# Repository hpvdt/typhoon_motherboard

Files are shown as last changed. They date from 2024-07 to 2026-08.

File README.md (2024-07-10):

# Typhoon Motherboard

General template repository for our hardware projects, especially one-off and self-contained projects like custom test equipment. This template assumes that the hardware is being designed in KiCad.

## Organization

Pretty self-explanitory, put hardware related files into the `hardware` folder, firmware in the `firmware` folder. Other folders can be added as needed: for example a `media` folder is handy for storing pictures related to a project which can be used in documentation.

## Conventions

Partly for consistency, partly for functionality; please follow the following conventions:

- Try to keep folder names to single words and all lowercase
- Use underscores to separate words in names (e.g. `board_rev1`). **DO NOT USE SPACES! ESPECIALLY FOR FOLDERS CONTAINING CODE!** Spaces in file paths may cause issues in compilers and such so best to avoid them entirely.

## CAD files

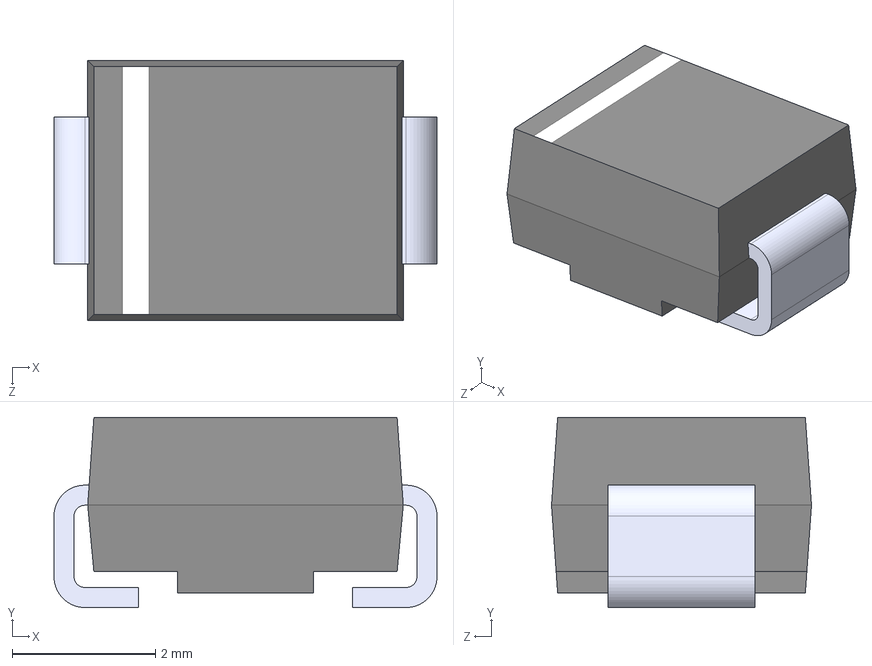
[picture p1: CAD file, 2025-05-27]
hardware/footprint/SMBJ5.0A/SMBJ5.0A.step
5.34 x 2.65 x 3.62 mm

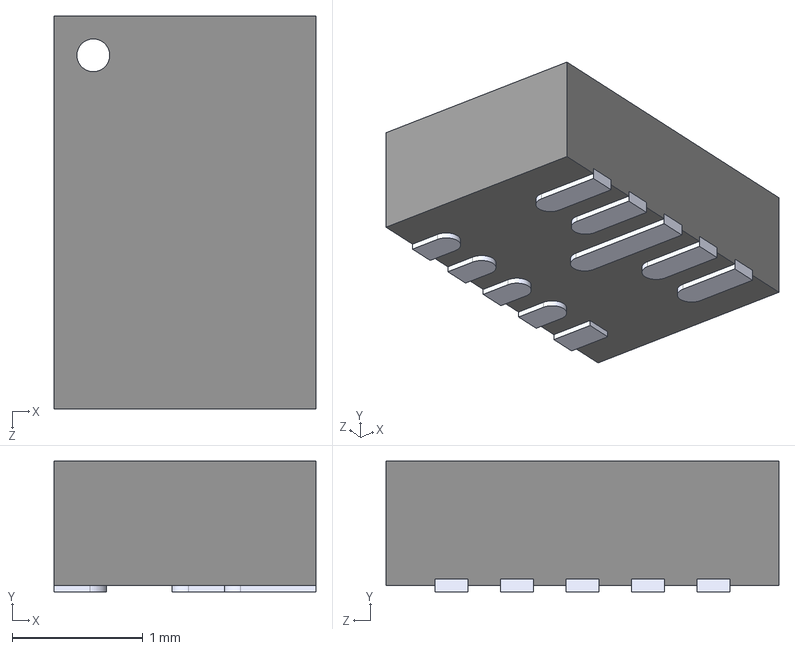
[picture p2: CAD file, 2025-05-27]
hardware/footprint/TPS63802DLAR (1)/TPS63802DLAR.step
2.00 x 1.00 x 3.00 mm

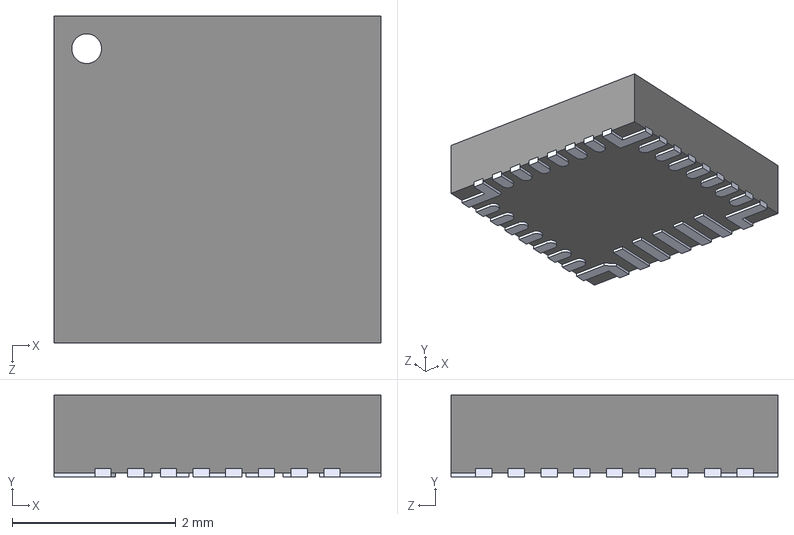
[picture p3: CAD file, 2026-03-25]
hardware/rev2/parts/BQ25798RQMR/BQ25798RQMR.step
4.00 x 1.00 x 4.00 mm

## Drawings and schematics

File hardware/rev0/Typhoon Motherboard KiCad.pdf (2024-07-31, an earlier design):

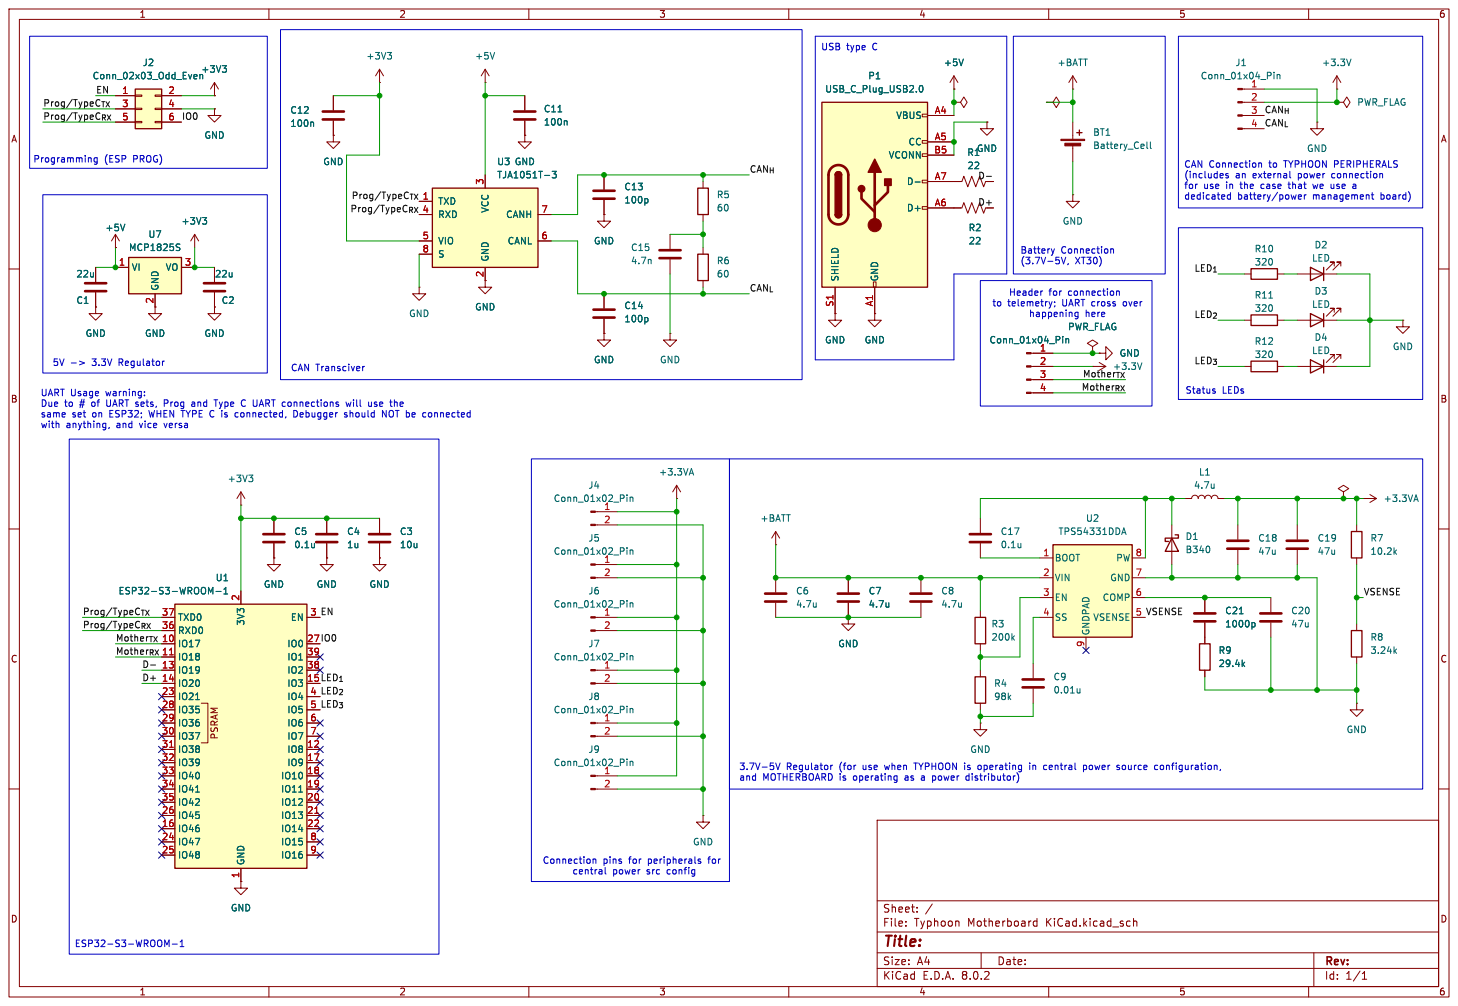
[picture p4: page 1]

for use in the case that we use a

3 RXD 4 VIO 5 CANL 6 CANH 7 S

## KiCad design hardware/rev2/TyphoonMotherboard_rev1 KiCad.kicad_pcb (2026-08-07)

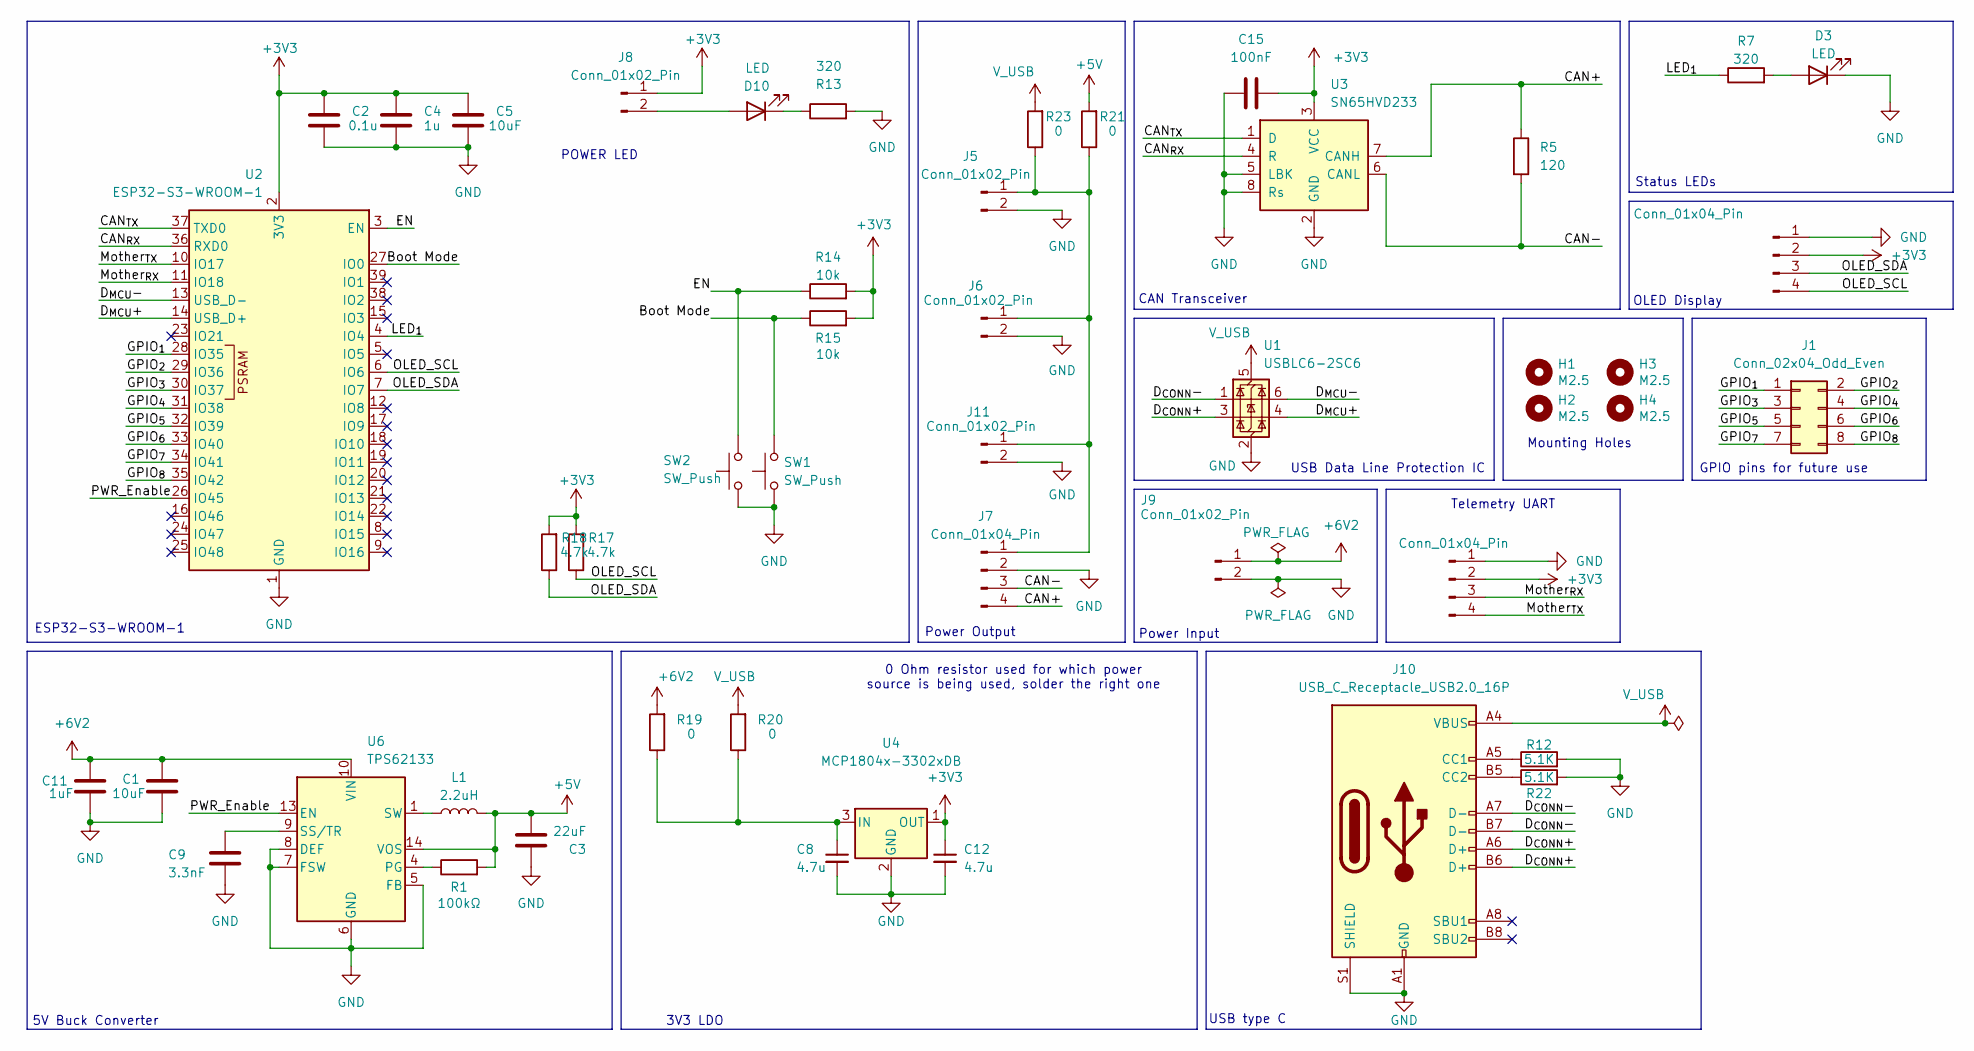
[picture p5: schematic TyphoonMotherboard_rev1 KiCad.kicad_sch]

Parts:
C1: 10uF; C_0603_1608Metric
C2: 0.1u; C_0603_1608Metric; Manufacturer Part Number CL10B105KP8NNNC
C3: 22uF; C_0603_1608Metric
C4: 1u; C_0603_1608Metric; Manufacturer Part Number C0603C104K5RACTU
C5: 10uF; C_0603_1608Metric; Manufacturer Part Number CL10A106KQ8NNNC
C8, C12: 4.7u; C_0603_1608Metric; LCSC C1779
C9: 3.3nF; C_0603_1608Metric
C11: 1uF; C_0603_1608Metric
C15: 100nF; C_0603_1608Metric; Manufacturer Part Number CL10E104KC8VPNC
D3, D10: LED; LED_0805_2012Metric; Manufacturer Part Number LTST-C171GKT
H1, H2, H3, H4: M2.5; MountingHole_2.7mm_M2.5
J1: Conn_02x04_Odd_Even; PinSocket_2x04_P2.54mm_Vertical
J2, J4, J7: Conn_01x04_Pin; JST_XH_B4B-XH-A_1x04_P2.50mm_Vertical
J5, J6, J9, J11: Conn_01x02_Pin; JST_XH_B2B-XH-A_1x02_P2.50mm_Vertical
J8: Conn_01x02_Pin; PinHeader_1x02_P2.54mm_Vertical
J10: USB_C_Receptacle_USB2.0_16P; USB_C_Receptacle_JAE_DX07S016JA1R1500; Manufacturer Part Number DX07S016JA3R1500
L1: 2.2uH; L_0805_2012Metric
R1: 100kΩ; R_0603_1608Metric
R5: 120; R_0603_1608Metric
R7: 320; R_0603_1608Metric; Manufacturer Part Number RT0603DRE07320RL
R12, R22: 5.1K; R_0603_1608Metric; Manufacturer Part Number RC0603FR-075K1L
R13: 320; R_0603_1608Metric; Manufacturer Part Number ERA-3AEB331V
R14, R15: 10k; R_0603_1608Metric; Manufacturer Part Number RMCF0603JT10K0
R17, R18: 4.7k; R_0603_1608Metric; Manufacturer Part Number RMCF0603JT10K0
R19, R20, R21, R23: 0; R_1206_3216Metric; Manufacturer Part Number RMCF0603JT10K0
SW1, SW2: SW_Push; SMT_FS
U1: USBLC6-2SC6; SOT-23-6; Manufacturer Part Number USBLC6-2SC6; Digikey Part Number 497-5235-1-ND
U2: ESP32-S3-WROOM-1; Manufacturer Part Number ESP32-S3-WROOM-1-N4R8
U3: SN65HVD233; SOIC-8_3.9x4.9mm_P1.27mm; Manufacturer Part Number SN65HVD233DR
U4: MCP1804x-3302xDB; SOT-223-3_TabPin2
U6: TPS62133; VQFN-16-1EP_3x3mm_P0.5mm_EP1.68x1.68mm_ThermalVias

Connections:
+3V3: C2.1, C4.1, C5.1, C12.1, C15.2, J2.2, J4.2, J8.1, R14.2, R15.2, R17.2, R18.2, U2.2 (3V3), U3.3 (VCC), U4.1 (OUT)
+5V: C3.2, L1.2, R1.2, R21.2, U6.14 (VOS)
+6V2: C1.2, C11.2, J9.1, R19.2, U6.10 (VIN), U6.11 (VIN), U6.12 (VIN)
/Boot Mode: R15.1, SW1.2, U2.27 (IO0)
/CAN+: J7.4, R5.1, U3.7 (CANH)
/CAN-: J7.3, R5.2, U3.6 (CANL)
/CAN_{RX}: U2.36 (RXD0), U3.4 (R)
/CAN_{TX}: U2.37 (TXD0), U3.1 (D)
/D_{CONN}+: J10.A6 (D+), J10.B6 (D+), U1.3 (I/O2)
/D_{CONN}-: J10.A7 (D-), J10.B7 (D-), U1.1 (I/O1)
/D_{MCU}+: U1.4 (I/O2), U2.14 (USB_D+)
/D_{MCU}-: U1.6 (I/O1), U2.13 (USB_D-)
/EN: R14.1, SW2.2, U2.3 (EN)
/GPIO_{1}: J1.1, U2.28 (IO35)
/GPIO_{2}: J1.2, U2.29 (IO36)
/GPIO_{3}: J1.3, U2.30 (IO37)
/GPIO_{4}: J1.4, U2.31 (IO38)
/GPIO_{5}: J1.5, U2.32 (IO39)
/GPIO_{6}: J1.6, U2.33 (IO40)
/GPIO_{7}: J1.7, U2.34 (IO41)
/GPIO_{8}: J1.8, U2.35 (IO42)
/LED_{1}: R7.1, U2.4 (IO4)
/Mother_{RX}: J2.3, U2.11 (IO18)
/Mother_{TX}: J2.4, U2.10 (IO17)
/OLED_SCL: J4.4, R17.1, U2.6 (IO6)
/OLED_SDA: J4.3, R18.1, U2.7 (IO7)
/PWR_Enable: U2.26 (IO45), U6.13 (EN)
GND: C1.1, C2.2, C3.1, C4.2, C5.2, C8.2, C9.1, C11.1, C12.2, C15.1, D3.1 (K), J2.1, J4.1, J5.2, J6.2, J7.2, J9.2, J10.A1 (GND), J10.A12 (GND), J10.B1 (GND), J10.B12 (GND), J10.S1 (SHIELD), J11.2, R12.2, R13.2, R22.2, SW1.1, SW2.1, U1.2 (GND), U2.1 (GND), U2.40 (GND), U2.41 (GND), U3.2 (GND), U3.5 (LBK), U3.8 (Rs), U4.2 (GND), U6.5 (FB), U6.6 (GND), U6.7 (FSW), U6.8 (DEF), U6.15 (GND), U6.16 (GND), U6.17 (GND)
unnamed: D3.2 (A), R7.2
unnamed: D10.2 (A), J8.2
unnamed: D10.1 (K), R13.1
unnamed: J10.A5 (CC1), R12.1
unnamed: J10.B5 (CC2), R22.1
unnamed: J5.1, J6.1, J7.1, J11.1, R21.1, R23.1
unnamed: L1.1, U6.1 (SW), U6.2 (SW), U6.3 (SW)
unnamed: C8.1, R19.1, R20.1, U4.3 (IN)
unnamed: R1.1, U6.4 (PG)
unnamed: C9.2, U6.9 (SS/TR)
V_USB: J10.A4 (VBUS), J10.A9 (VBUS), J10.B4 (VBUS), J10.B9 (VBUS), R20.2, R23.2, U1.5 (VBUS)

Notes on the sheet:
Status LEDs
Power Input
ESP32-S3-WROOM-1
USB Data Line Protection IC
CAN Transceiver
5V Buck Converter
3V3 LDO
OLED Display
GPIO pins for future use
Mounting Holes
Power Output
POWER LED
0 Ohm resistor used for which power source is being used, solder the right one
USB type C
Telemetry UART

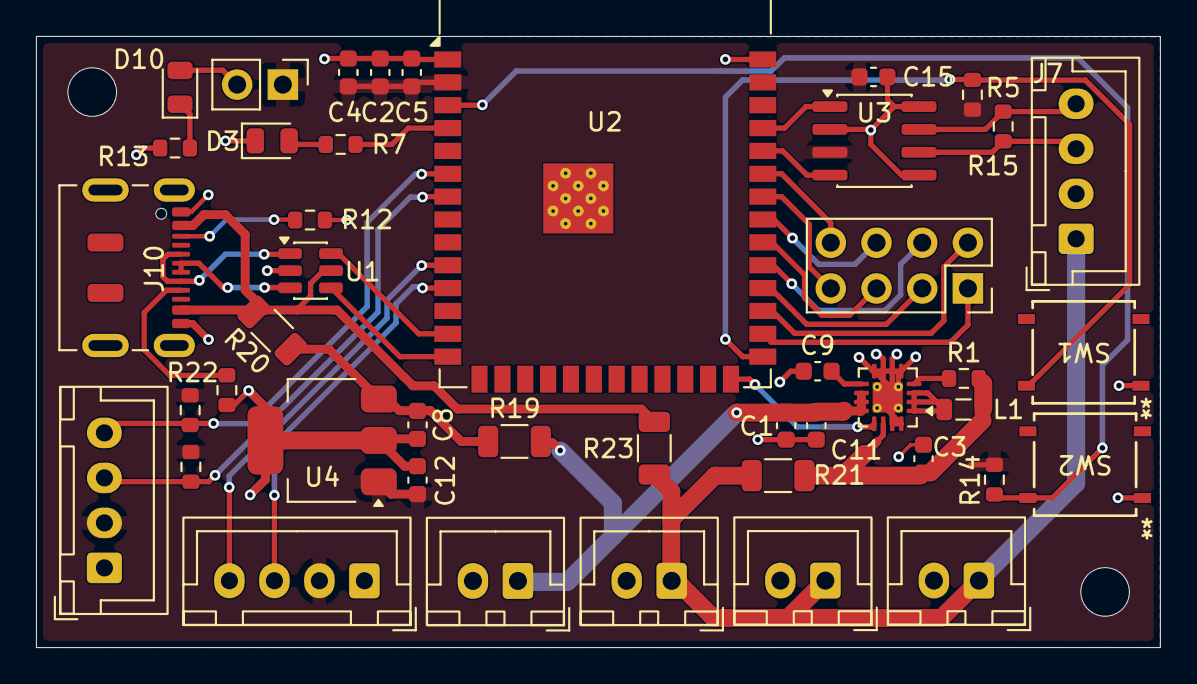
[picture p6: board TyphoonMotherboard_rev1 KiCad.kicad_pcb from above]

Board: 2 copper layers, 62.4 x 33.9 mm, 48 parts (0 on the bottom side), 39 nets.

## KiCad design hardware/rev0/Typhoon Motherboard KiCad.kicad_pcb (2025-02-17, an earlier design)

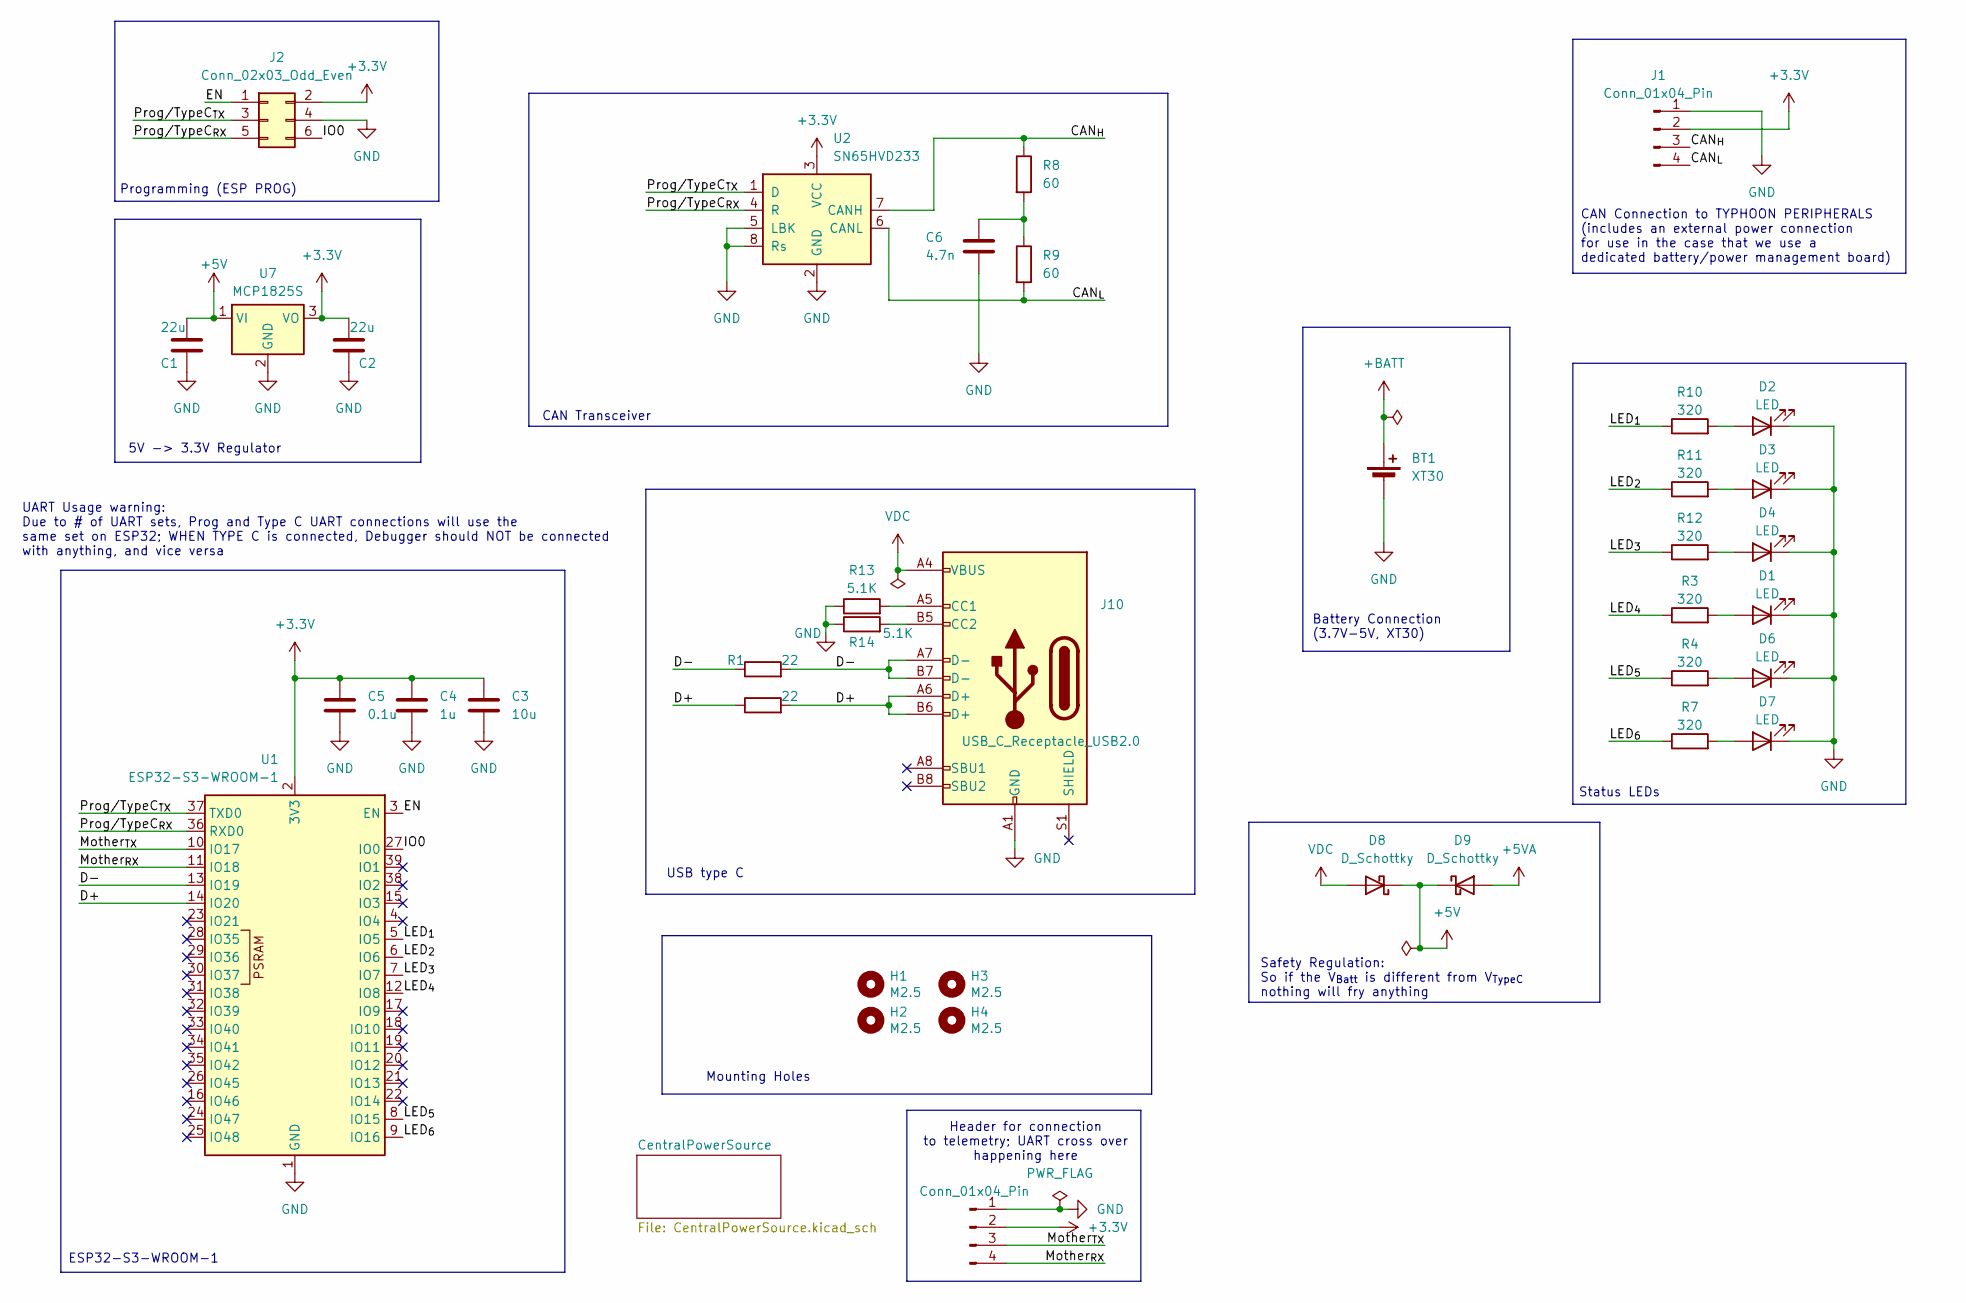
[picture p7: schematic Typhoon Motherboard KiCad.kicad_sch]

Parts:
BT1: XT30; AMASS_XT30PW-M_1x02_P2.50mm_Horizontal
C1, C2: 22u; C_0603_1608Metric
C3: 10u; C_0603_1608Metric
C4: 1u; C_0603_1608Metric
C5: 0.1u; C_0603_1608Metric
C6: 4.7n; C_0603_1608Metric
D1, D2, D3, D4, D6, D7: LED; LED_0805_2012Metric
D8, D9: D_Schottky; D_SOD-123
H1, H2, H3, H4: M2.5; MountingHole_2.7mm_M2.5
J1: Conn_01x04_Pin; JST_EH_S4B-EH_1x04_P2.50mm_Horizontal
J2: Conn_02x03_Odd_Even; IDC-Header_2x03_P2.54mm_Vertical
J3: Conn_01x04_Pin; PinHeader_1x04_P1.27mm_Vertical
J10: USB_C_Receptacle_USB2.0; USB_C_Receptacle_HRO_TYPE-C-31-M-12
R1, R2: 22; R_0603_1608Metric
R3, R4, R7, R10, R11, R12: 320; R_0603_1608Metric
R8, R9: 60; R_0603_1608Metric
R13, R14: 5.1K; R_0603_1608Metric
U1: ESP32-S3-WROOM-1
U2: SN65HVD233; SOIC-8_3.9x4.9mm_P1.27mm
U7: MCP1825S; SOT-223-3_TabPin2

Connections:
+3.3V: C2.2, C3.1, C4.1, C5.1, J1.2, J2.2, J3.2, U1.2 (3V3), U2.3 (VCC), U7.3 (VO)
+5V: C1.2, D8.1 (K), D9.1 (K), U7.1 (VI)
+5VA: D9.2 (A); also elsewhere on the board
+BATT: BT1.1 (+); also elsewhere on the board
/CAN_{H}: J1.3, R8.1, U2.7 (CANH)
/CAN_{L}: J1.4, R9.2, U2.6 (CANL)
/EN: J2.1, U1.3 (EN)
/IO0: J2.6, U1.27 (IO0)
/LED_{1}: R10.1, U1.5 (IO5)
/LED_{2}: R11.1, U1.6 (IO6)
/LED_{3}: R12.1, U1.7 (IO7)
/LED_{4}: R3.1, U1.12 (IO8)
/LED_{5}: R4.1, U1.8 (IO15)
/LED_{6}: R7.1, U1.9 (IO16)
/Mother_{RX}: J3.4, U1.11 (IO18)
/Mother_{TX}: J3.3, U1.10 (IO17)
/Prog/TypeC_{RX}: J2.5, U1.36 (RXD0), U2.4 (R)
/Prog/TypeC_{TX}: J2.3, U1.37 (TXD0), U2.1 (D)
GND: BT1.2 (-), C1.1, C2.1, C3.2, C4.2, C5.2, C6.2, D1.1 (K), D2.1 (K), D3.1 (K), D4.1 (K), D6.1 (K), D7.1 (K), J1.1, J2.4, J3.1, J10.A1 (GND), J10.A12 (GND), J10.B1 (GND), J10.B12 (GND), R13.1, R14.1, U1.1 (GND), U1.40 (GND), U1.41 (GND), U2.2 (GND), U2.5 (LBK), U2.8 (Rs), U7.2 (GND); also elsewhere on the board
unnamed: C6.1, R8.2, R9.1
unnamed: D1.2 (A), R3.2
unnamed: D2.2 (A), R10.2
unnamed: D3.2 (A), R11.2
unnamed: D4.2 (A), R12.2
unnamed: D6.2 (A), R4.2
unnamed: D7.2 (A), R7.2
unnamed: J10.A5 (CC1), R13.2
unnamed: J10.B5 (CC2), R14.2
VDC: D8.2 (A), J10.A4 (VBUS), J10.A9 (VBUS), J10.B4 (VBUS), J10.B9 (VBUS)

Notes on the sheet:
Header for connection to telemetry; UART cross over happening here
Battery Connection (3.7V-5V, XT30)
Programming (ESP PROG)
Status LEDs
CAN Connection to TYPHOON PERIPHERALS (includes an external power connection for use in the case that we use a dedicated battery/power management board)
Safety Regulation: So if the V_{Batt} is different from V_{TypeC} nothing will fry anything
Mounting Holes
5V -> 3.3V Regulator
USB type C
ESP32-S3-WROOM-1
CAN Transceiver
UART Usage warning: Due to # of UART sets, Prog and Type C UART connections will use the same set on ESP32; WHEN TYPE C is connected, Debugger should NOT be connected with anything, and vice versa

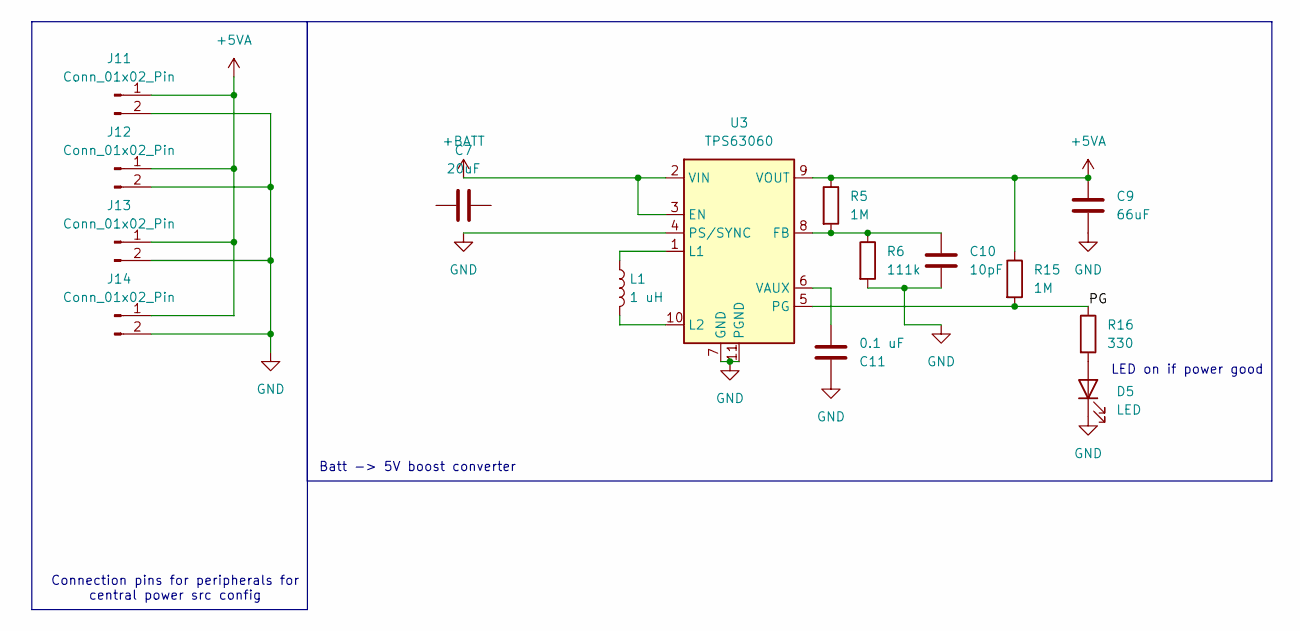
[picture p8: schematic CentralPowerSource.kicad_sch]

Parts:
C7: 20uF; C_0603_1608Metric
C9: 66uF; C_0603_1608Metric
C10: 10pF; C_0603_1608Metric
C11: 0.1 uF; C_0603_1608Metric
D5: LED; LED_0805_2012Metric
J11, J12, J13, J14: Conn_01x02_Pin; JST_EH_S2B-EH_1x02_P2.50mm_Horizontal
L1: 1 uH; L_0805_2012Metric
R5, R15: 1M; R_0603_1608Metric
R6: 111k; R_0603_1608Metric
R16: 330; R_0603_1608Metric
U3: TPS63060; Texas_S-PWSON-N10_ThermalVias

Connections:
+5VA: C9.1, J11.1, J12.1, J13.1, J14.1, R5.1, R15.1, U3.9 (VOUT); also elsewhere on the board
+BATT: U3.2 (VIN), U3.3 (EN); also elsewhere on the board
/CentralPowerSource/PG: R15.2, R16.1, U3.5 (PG)
GND: C9.2, C10.2, C11.1, D5.1 (K), J11.2, J12.2, J13.2, J14.2, R6.2, U3.4 (PS/SYNC), U3.7 (GND), U3.11 (PGND); also elsewhere on the board
unnamed: D5.2 (A), R16.2
unnamed: C10.1, R5.2, R6.1, U3.8 (FB)
unnamed: L1.1, U3.1 (L1)
unnamed: L1.2, U3.10 (L2)
unnamed: C11.2, U3.6 (VAUX)

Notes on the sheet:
Batt -> 5V boost converter
Connection pins for peripherals for central power src config
LED on if power good

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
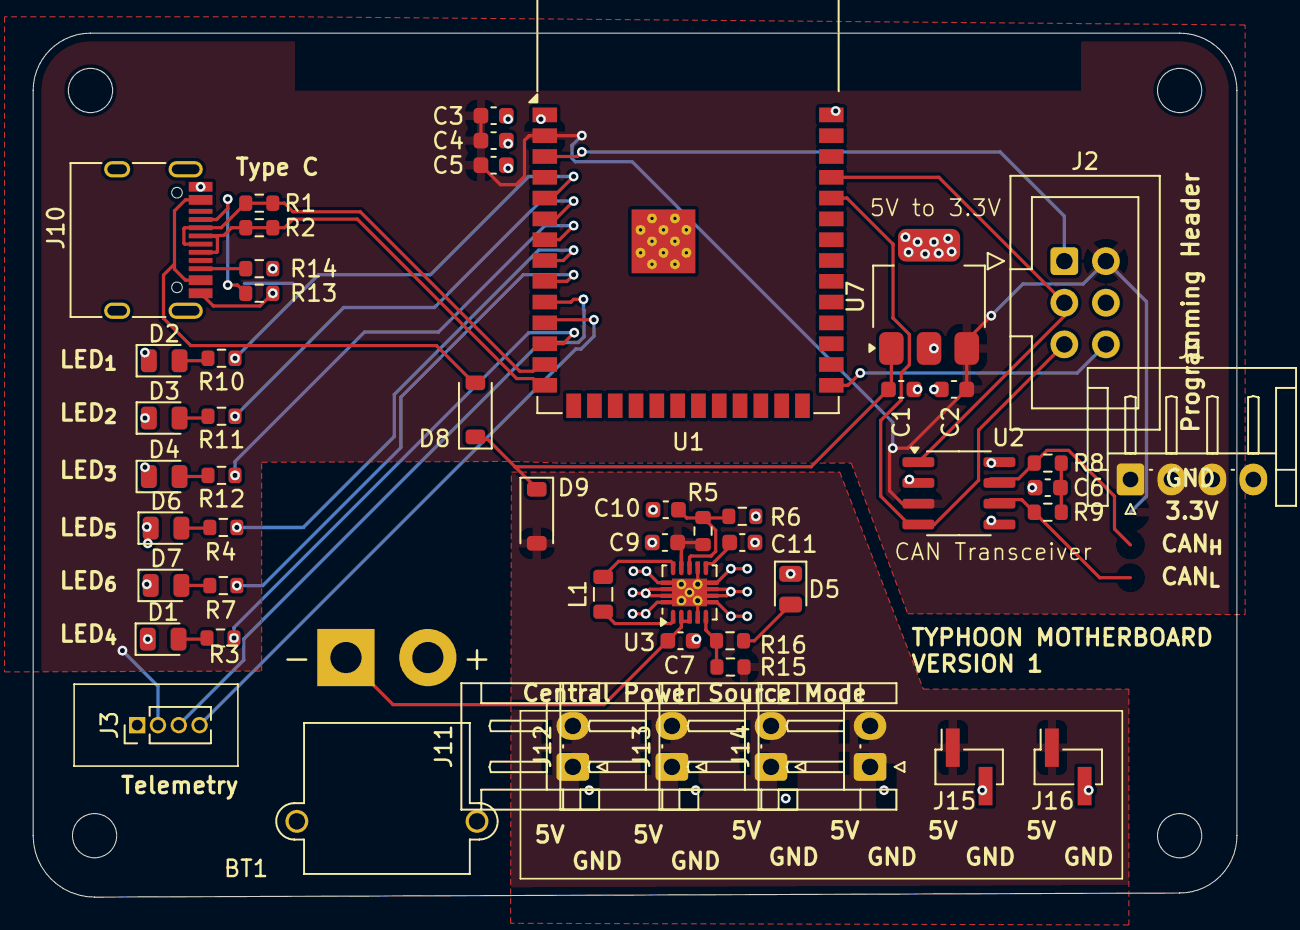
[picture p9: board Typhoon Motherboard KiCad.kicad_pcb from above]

Board: 2 copper layers, 73.5 x 52.8 mm, 55 parts (0 on the bottom side), 39 nets.

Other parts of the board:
J15, J16: Conn_01x02_Pin; PinHeader_1x02_P2.00mm_Vertical_SMD_Pin1Right

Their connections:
+5VA: J15.1, J16.1; also elsewhere on the board
GND: J15.2, J16.2; also elsewhere on the board

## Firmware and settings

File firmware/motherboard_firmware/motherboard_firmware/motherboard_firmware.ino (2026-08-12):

#include <Arduino.h>
#include "driver/twai.h"

constexpr gpio_num_t CAN_TX_PIN = GPIO_NUM_43;
constexpr gpio_num_t CAN_RX_PIN = GPIO_NUM_44;

constexpr uint32_t LED_COMMAND_ID = 0x200;
constexpr uint32_t LED_STATUS_ID  = 0x201;

void setup()
{
    Serial.begin(115200);
    delay(1000);

    twai_general_config_t generalConfig =
        TWAI_GENERAL_CONFIG_DEFAULT(
            CAN_TX_PIN,
            CAN_RX_PIN,
            TWAI_MODE_NORMAL
        );

    twai_timing_config_t timingConfig =
        TWAI_TIMING_CONFIG_500KBITS();

    twai_filter_config_t filterConfig =
        TWAI_FILTER_CONFIG_ACCEPT_ALL();

    if (twai_driver_install(
            &generalConfig,
            &timingConfig,
            &filterConfig
        ) != ESP_OK) {

        Serial.println("CAN installation failed");

        while (true)
            delay(1000);
    }

    if (twai_start() != ESP_OK) {
        Serial.println("CAN start failed");

        while (true)
            delay(1000);
    }

    Serial.println("CAN LED controller started");
}

void loop()
{
    static bool ledOn = false;
    static uint8_t sequence = 0;

    ledOn = !ledOn;

    twai_message_t command = {};

    command.identifier = LED_COMMAND_ID;
    command.data_length_code = 2;

    command.data[0] = ledOn ? 1 : 0;
    command.data[1] = sequence;

    if (twai_transmit(
            &command,
            pdMS_TO_TICKS(100)
        ) == ESP_OK) {

        Serial.print("LED command sent: ");
        Serial.println(ledOn ? "ON" : "OFF");
    }
    else {
        Serial.println("LED command failed");
    }

    twai_message_t response = {};

    if (twai_receive(
            &response,
            pdMS_TO_TICKS(500)
        ) == ESP_OK) {

        if (response.identifier == LED_STATUS_ID &&
            response.data_length_code >= 2 &&
            response.data[1] == sequence) {

            Serial.print("Receiver confirmed LED: ");
            Serial.println(response.data[0] ? "ON" : "OFF");
        }
    }
    else {
        Serial.println("No response from receiver");
    }

    sequence++;

    delay(1000);
}

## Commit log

2024-07-12 coped files from old typhoon electronics repo into this new repo which is dedicated to only typhoon motherboard
    [Typhoon Motherboard KiCad.kicad_pcb, Typhoon Motherboard KiCad.kicad_sch]
2024-07-28 first version of motherboard schematic
    [Typhoon Motherboard KiCad.kicad_sch]
2024-07-28 added notes
    [Typhoon Motherboard KiCad.kicad_sch]
2024-07-31 Rev 2 upload
    [Typhoon Motherboard KiCad.kicad_sch]
2024-07-31 revision 1 by savo
    [Typhoon Motherboard KiCad.kicad_sch]
2024-07-31 create new sheet; update USBC
    created new sheet for the central power source configuration so it's more organized; updated the USB-C symbol; added in safety regulations (diodes) to prevent conflict in voltages
    [CentralPowerSource.kicad_sch, Typhoon Motherboard KiCad.kicad_sch]
2024-08-01 Everything written in the schematic
    [Typhoon Motherboard KiCad.kicad_sch]
2024-09-04 Update Schematics and Start PCB
    [CentralPowerSource.kicad_sch, Typhoon Motherboard KiCad.kicad_pcb, Typhoon Motherboard KiCad.kicad_sch]
2024-09-04 First draft of PCB
    [Typhoon Motherboard KiCad.kicad_pcb]
2024-09-05 Finalized First Draft of the PCB
    [Typhoon Motherboard KiCad.kicad_pcb]
2024-09-05 Fixed Placement issues (aesthetic fixes)
    [Typhoon Motherboard KiCad.kicad_pcb]
2024-09-06 Update (Round Edges)
    [Typhoon Motherboard KiCad.kicad_pcb]
2024-09-07 Added mounting holes
    [Typhoon Motherboard KiCad.kicad_pcb]
2024-10-05 Updated header (NOT FINAL)
    [Typhoon Motherboard KiCad.kicad_pcb, Typhoon Motherboard KiCad.kicad_sch]
2024-10-08 Final Edit
    [Typhoon Motherboard KiCad.kicad_pcb]
2024-10-31 Updated the Boost Converter
    [CentralPowerSource.kicad_sch, Typhoon Motherboard KiCad.kicad_pcb, Typhoon Motherboard KiCad.kicad_sch]
2024-11-17 Production Files
    [CentralPowerSource.kicad_sch, Typhoon Motherboard KiCad.kicad_pcb, Typhoon Motherboard KiCad.kicad_sch]
2025-02-17 Updated Rev 1
    [CentralPowerSource.kicad_sch, Typhoon Motherboard KiCad.kicad_pcb, Typhoon Motherboard KiCad.kicad_sch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]
2025-02-27 Updated Voltage Regulation
    [TyphoonMotherboard_rev1 KiCad.kicad_sch]
2025-05-27 Rev1 Fully Finalized
    [SMBJ5.0A.step, TPS63802DLAR.step, TyphoonMotherboard_rev1 KiCad.kicad_pcb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]
2026-01-11 Blinky Example Creation
    [TyphoonMotherboard_rev1 KiCad.kicad_sch]
2026-01-22 Updated the Symbol Fields for Motherboard
    [TyphoonMotherboard_rev1 KiCad.kicad_sch]
2026-02-10 Matched the CAN test to STM32 (speed and cadence) instead of Loopback
    [TyphoonMotherboard_rev1 KiCad.kicad_sch]
2026-03-24 rev2 for new revision
    [TyphoonMotherboard_rev1 KiCad.kicad_pcb, TyphoonMotherboard_rev1 KiCad.kicad_sch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]
2026-03-25 worked on pmic schematic
    [BQ25798RQMR.step, TyphoonMotherboard_rev1 KiCad.kicad_sch]
2026-03-29 pmic and voltage regulator schematic updates
    [TyphoonMotherboard_rev1 KiCad.kicad_sch]
2026-04-07 Reviewed the Schematic making PCB
    [TyphoonMotherboard_rev1 KiCad.kicad_sch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]
2026-05-16 removed updates
    [TyphoonMotherboard_rev1 KiCad.kicad_pcb, TyphoonMotherboard_rev1 KiCad.kicad_sch]
2026-05-19 Updated rev2 voltage regulation schematic (TP62133 regulator)
    [TyphoonMotherboard_rev1 KiCad.kicad_sch]
2026-05-19 Finished Schematic Ready for PCB Design
    [TyphoonMotherboard_rev1 KiCad.kicad_sch]
2026-05-19 some other small changes
    [TyphoonMotherboard_rev1 KiCad.kicad_pcb]
2026-06-06 <UPDATE> Oliver Review Ver
    [TyphoonMotherboard_rev1 KiCad.kicad_pcb, TyphoonMotherboard_rev1 KiCad.kicad_sch]
2026-08-07 <UPDATE> Ordered Board
    [TyphoonMotherboard_rev1 KiCad-B_Cu.gbr, TyphoonMotherboard_rev1 KiCad-B_Mask.gbr, TyphoonMotherboard_rev1 KiCad-B_Paste.gbr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]
2026-08-12 <UPDATE> Got CAN Tran. working
    - Confirm CAN system is working with lighting, will work towards all the functions of the board
